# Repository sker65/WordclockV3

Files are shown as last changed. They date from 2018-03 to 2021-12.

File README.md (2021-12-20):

# Links
http://www.leuchtbildshop.net/                                              - Material (Diffusionsfolie)

http://diskussion.christians-bastel-laden.de/index.php                      - Forum (Anleitungen, Folienlieferanten etc)

https://www.mikrocontroller.net/articles/WordClock_mit_WS2812#Frontplatten  - alternative Version (mehr Funktionen)

# changes / extensions by sker65

- added some alternative mapping tables for other word positions (for now only compile time switches)
- added random mode for transitions
- added rainbow color mode.
- added alternative way of spelling minutes (dreiviertel vs. viertel vor)
- make constant "Es ist" display switchable
- code refactored to run with neopixel bus (https://github.com/Makuna/NeoPixelBus) to avoid flickering
- "PROGMEM" aligned to 4 to avoid unaligned access exception
- added new snake transition
- added switch off at night time feature
- cleanup weg ui / JS
- added fill modes for background filling to not just reset the background (big brightness change)
- added moon phase rendering

## compile with arduino ide
to compile with arduino ide install board type "wemos d1 mini" or compatible and install some libraries:
- ArduinoOTA
- ESP8266WiFi
- DNSServer
- ESP8266WebServer
- ESP8266mDNS
- Ticker
- WiFiManager
- NeoPixelBus_by_Makuna
- SPI (maybe alredy core)
- EEPROM (maybe already core)
- ArduinoJson (to be removed, only needed for output redering)
# esp8266wordclock
Wordclock with WS2812B RGB LED modules driven by an ESP8266 module

This is my interpretation of the popular wordclock project. Key features:

- runs on ESP8266 (ESP-07)
- using Arduino framework
- 114 WS2812B LEDs (driven by neopixel bus (formerly AdaFruit_NeoPixel) library)
- WiFi connected
- WiFiManager allows for easy configuration when WiFi network is not yet configured
- NTP client regularly fetches time
- integrated web server handles configuration interface for colors, time server etc.
- automatic brightness using LDR 

front
front

The clock is built into an [IKEA Ribba picture frame](http://www.ikea.com/de/de/catalog/products/00078051/) (€5), the front plate is screen printed to get fully opaque and sharp mask. The time is displayed using words with five minute resolution and the LEDs in the four corners display the minutes between the word changes. Seconds are visualized using the background slowly filling with an alternative color (configurable using the Web interface).



The configuration interface is accessible using any browser at the URL http://wordclock.local and allows to change foreground color, background color, the seconds progress color and other options.

back

The ESP8266 has been wired in dead bug style, I didn't bother to create a PCB for that. [Modules with integrated voltage regulator, buttons, USB and LDR](http://www.cnx-software.com/2015/12/14/3-compact-esp8266-board-includes-rgd-led-photo-resistor-buttons-and-a-usb-to-ttl-interface/) would have been a better option, but delivery from China is so slow and I didn't want to wait that long. The WS2812B LEDs are wired using thin copper wire. When fully powered, the voltage drop on the power wires is quite high and the last LEDs in the chain don't get enough voltage and stop responding. In the next version, I will use thicker wire for the power lines.

The base for the LEDs is made of MDF milled on my CNC mill. It consists of a 12 mm back plate with holes and small rims for the LEDs to rest on and a 12 mm front plate having holes with equal diameter. I added a first diffusor of thin paper between the two plates (to make the LED less visible) and painted the inside of the holes white. On top I added a second diffusor (plastic foil) so the light tunnel gets invisible.

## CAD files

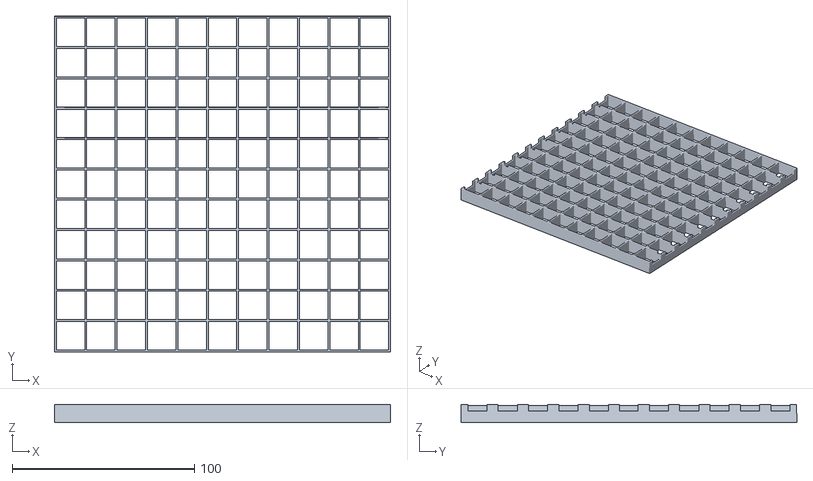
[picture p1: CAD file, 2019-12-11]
_Worldclock 3d Print/Komplett druckbar/3d files/wordclock-grid-complete.stl
184.4 x 184.3 x 10.0

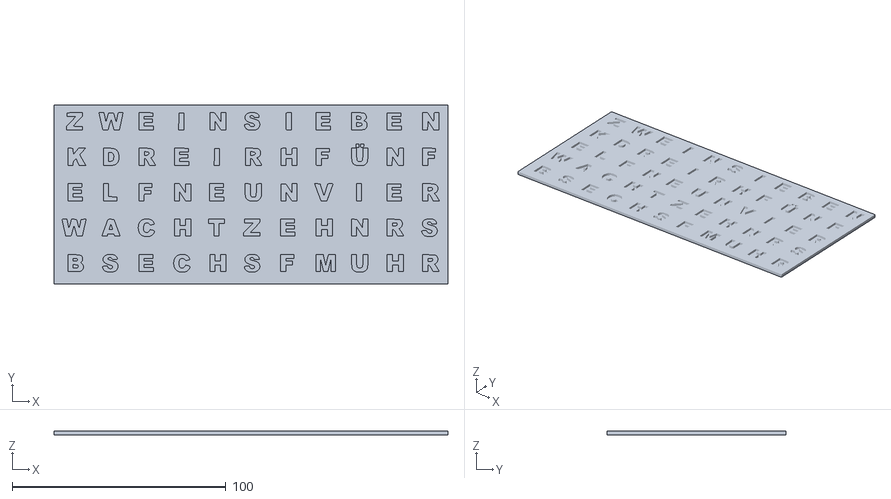
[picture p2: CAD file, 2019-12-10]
_Worldclock 3d Print/Komplett druckbar/3d files/wordclock_shade_full_normal_lower_half.stl
184.4 x 83.8 x 1.80

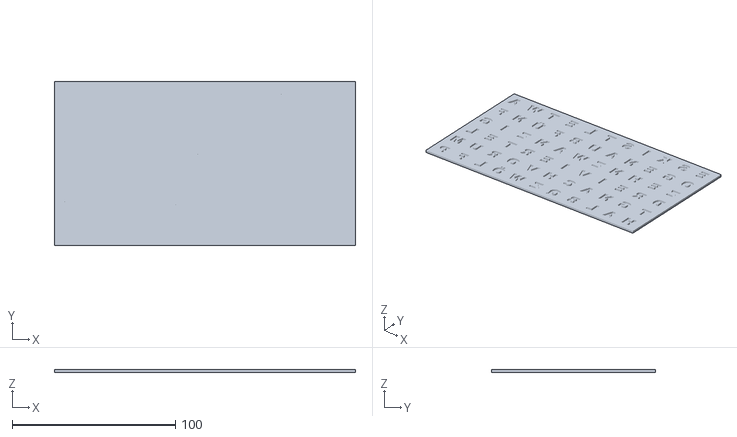
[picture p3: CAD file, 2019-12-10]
_Worldclock 3d Print/Komplett druckbar/3d files/wordclock_shade_full_mirror_upper_half.stl
184.4 x 100.6 x 1.80

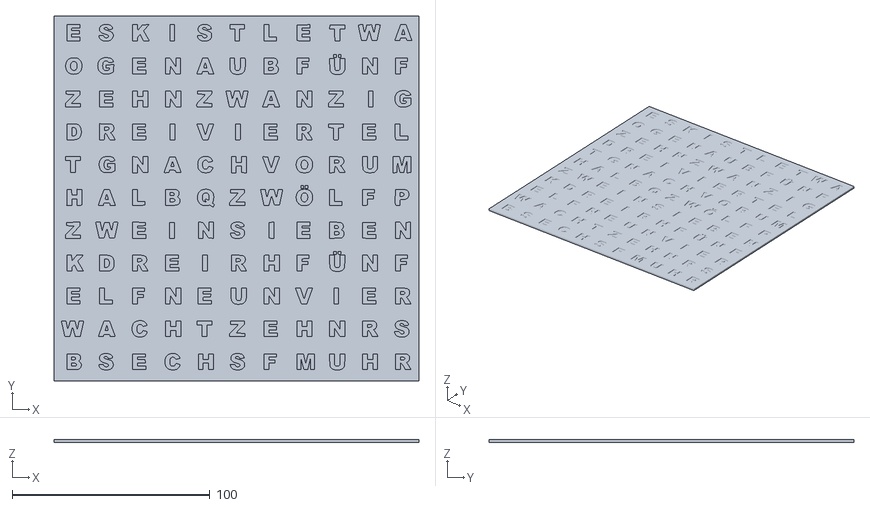
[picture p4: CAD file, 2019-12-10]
_Worldclock 3d Print/Komplett druckbar/3d files/wordclock_shade_full_normal.stl
184.4 x 184.4 x 1.40

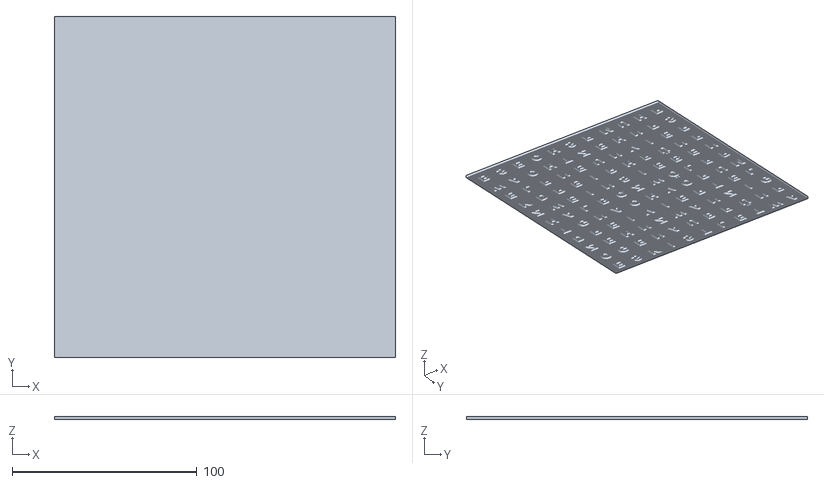
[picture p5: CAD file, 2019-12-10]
_Worldclock 3d Print/Komplett druckbar/3d files/wordclock_shade_full_mirror.stl
184.4 x 184.4 x 1.80

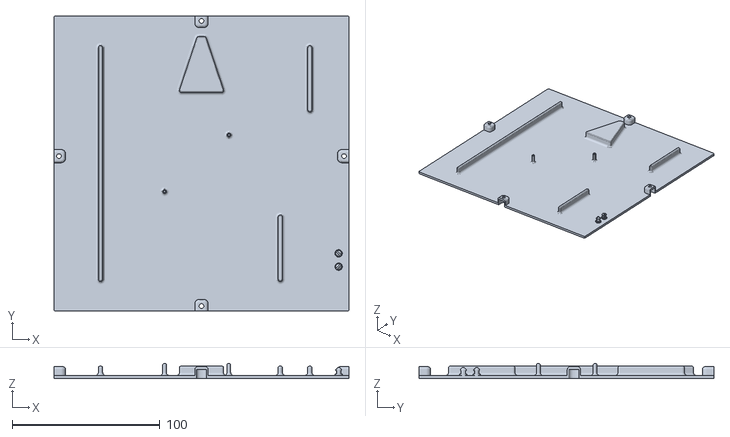
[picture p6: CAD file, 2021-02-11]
_Worldclock 3d Print/druckbar 2/files/Wordclock_Backplate.stl
199.7 x 199.7 x 10.0

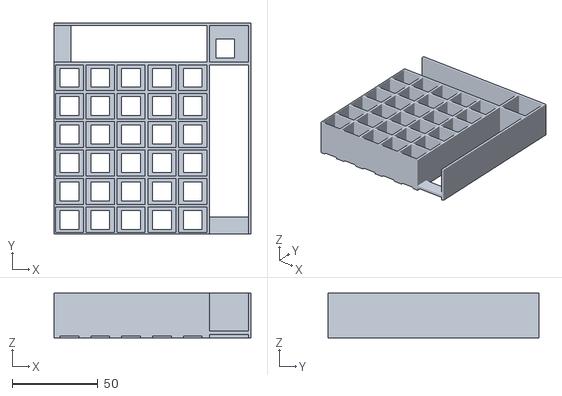
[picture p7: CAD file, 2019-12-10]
_Worldclock 3d Print/für Ikea Rahmen/Lichtgitter1_2x.stl
115.0 x 123.3 x 26.0

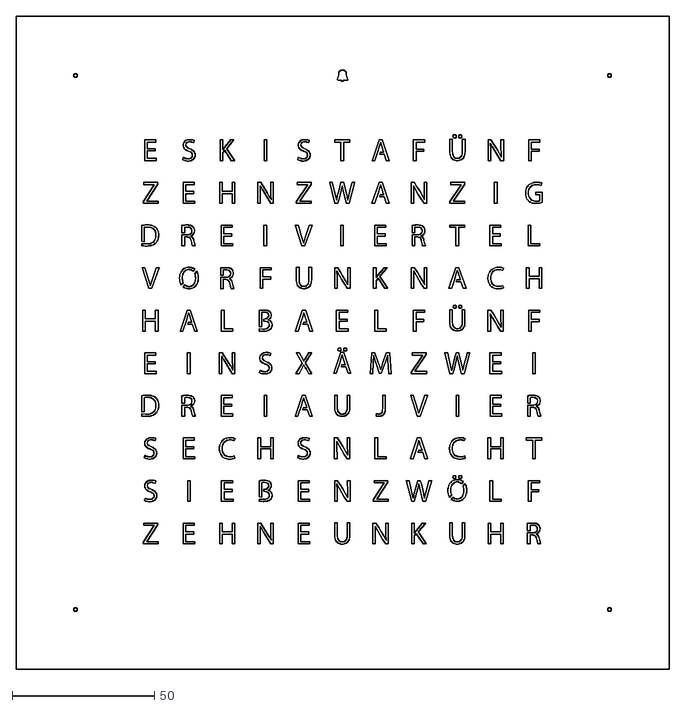
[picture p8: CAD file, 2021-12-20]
Graphics/wortuhr_klein_wecker_frontplatte.dxf
229.9 x 229.9

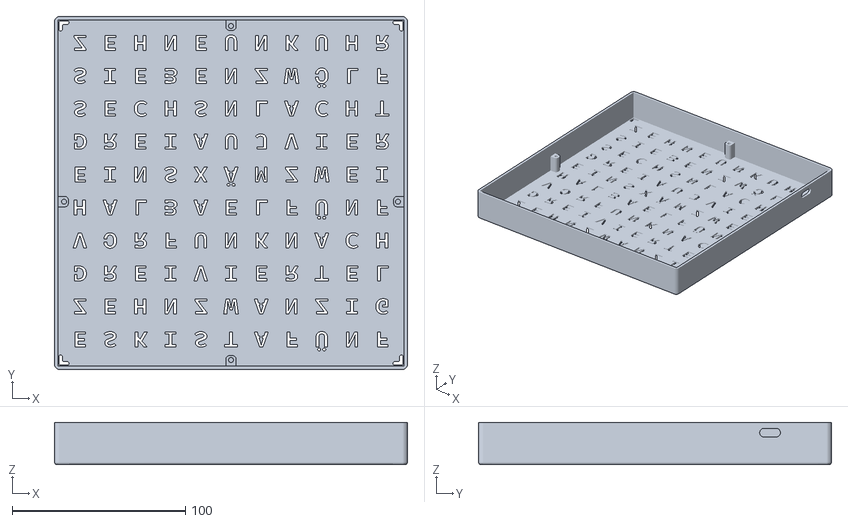
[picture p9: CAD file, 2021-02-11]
_Worldclock 3d Print/druckbar 2/files/Wordclock_Frontcover.stl
204.0 x 204.0 x 24.5

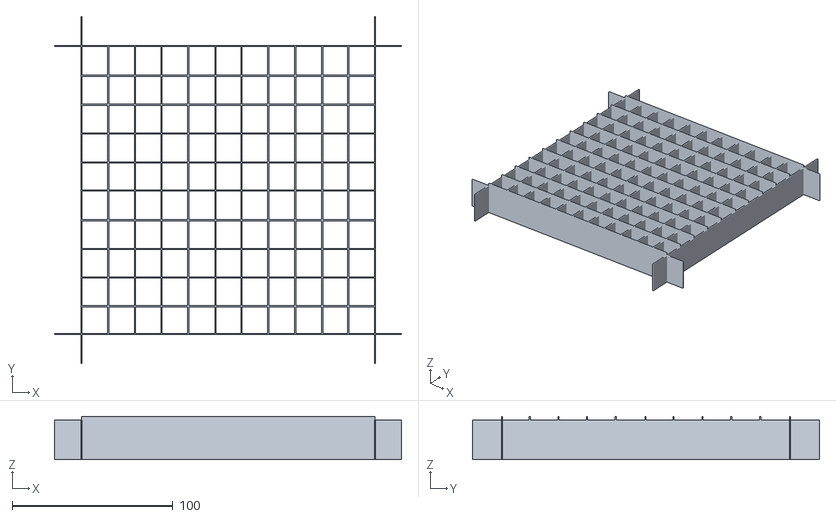
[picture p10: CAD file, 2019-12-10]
_Worldclock 3d Print/für Ikea Rahmen/Wortuhr_Ikea_Lichtgitter.stl
216.0 x 216.0 x 27.0

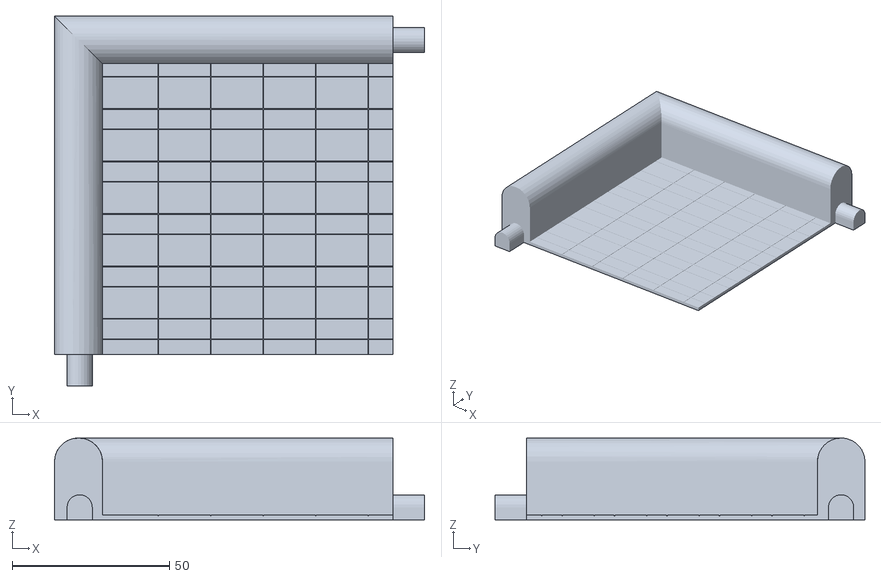
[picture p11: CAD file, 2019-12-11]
_Worldclock 3d Print/Komplett druckbar/3d files/wordclock-case_quater2.stl
117.5 x 117.5 x 26.0

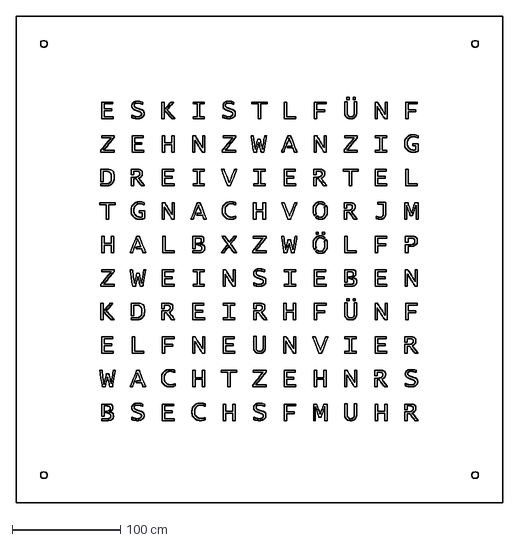
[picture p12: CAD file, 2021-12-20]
Graphics/EdelstahlFrontV2_Faktor10_vergroessert.dxf
450.0 x 450.0 cm

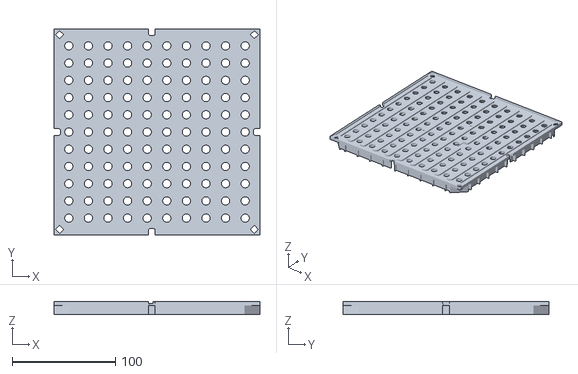
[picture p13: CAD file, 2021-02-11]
_Worldclock 3d Print/druckbar 2/files/wordclock_interior.stl
199.7 x 199.7 x 13.0

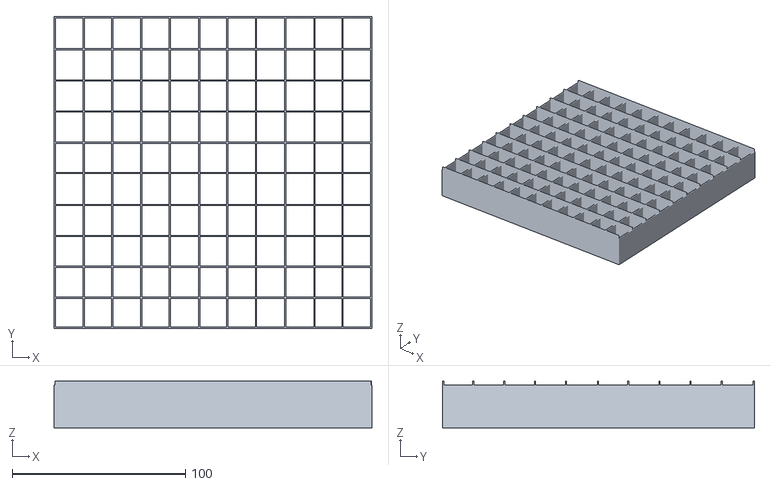
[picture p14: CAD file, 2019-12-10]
_Worldclock 3d Print/für Ikea Rahmen/Wortuhr_Ikea_Lichtgitter passend für drucker.stl
183.5 x 180.2 x 27.0

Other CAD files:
_Worldclock 3d Print/Komplett druckbar/3d files/wordclock_shade_full_mirror_lower_half.stl
_Worldclock 3d Print/Komplett druckbar/3d files/wordclock_shade_full_normal_upper_half.stl
_Worldclock 3d Print/Komplett druckbar/3d files/wordclock-case_quater1.stl
Graphics/Clock_45x45.dxf
.Material/dxfs/180222 T HC Frontplatte groß.dwg
.Material/dxfs/180222 T HC Frontplatte groß.dxf
.Material/dxfs/180222 T HC WordClock Rasterbleche.dwg
.Material/dxfs/180222 T HC WordClock Rasterbleche.dxf
Graphics/EdelstahlFrontV2.dxf
_Worldclock 3d Print/Komplett druckbar/3d files/wordclock-bottom-grid_half.stl
_Worldclock 3d Print/Komplett druckbar/3d files/wordclock-case.stl
_Worldclock 3d Print/Komplett druckbar/3d files/wordclock-case_half.stl
_Worldclock 3d Print/Komplett druckbar/3d files/wordclock-upper-grid_half.stl
_Worldclock 3d Print/Komplett druckbar/3d files/wordclock_shade.stl
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

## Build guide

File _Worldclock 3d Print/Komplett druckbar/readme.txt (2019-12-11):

This is a fully printable case for a word-clock. It is designed for use of LED stripes WS281x with 60 LED/m.
Additional there are needed only a RaspberryPi, a 5V power-supply, some wires and the software from here: https://github.com/xSnowHeadx/word-clock
If using an additional USB-soundcard the device can be used as spectrum-analyzer too (see third picture).

Edit 2017/02/28: wordclock_case_half.stl updated

Edit 2018/08/15: now the cheaper ESP8266 can be used instead the expensive RaspberryPi. A first try of the software is available here: https://github.com/xSnowHeadx/WordClock_ESP8266. There are no audio-functions and (at the moment) no moodlight modus supportet. I also designed a fitting case for the ESP8266: https://www.thingiverse.com/thing:2842012

Print Settings
Printer:

FlashForge Dreamer

Rafts:

No

Supports:

No

Notes:
Print two pieces of the half outer case. On the bottom of the case there are marks for the placement of the LED stripes.
For the grid laying direct on the LED stripes use the parts "bottom_grid". They have slots for the stripes and wires. You need two of them. The upper grids are without slots for better shadowing. Here are 4 pieces necessary. These parts are not at double height to give the possibility for placing additional diffusor foils between them when using a clear shade. Print the grids with black material.
The size of the shades is 184x184mm. If your printer has a sufficient build volume you can use the single parts. If not, use the halved parts. The grids are generally halved for better insertion in the case.

I uploaded all thinkable variants of the shades for your convenience. They must be printed with a resolution of 0.2mm and usually with the plate downwards. The first two layers (the plate) must be printed with a transparent or translucent material. After the second layer the filament has to be changed to black.
The types "normal" can be used, when the letters should be visible even if they are not lighted to show the functionality.
The "mirror" types can be used to hide the letters and show only the lighted. With a translucent white plate and a turquois light setting (RGB 0%,78%,100%) there is an "Apple-effect" possible as to see in the photos.
If you want to use your own print strategy I uploaded the shade for the letters and the plate for the shade separate.
If you don't want to print the shade with the 3D-printer you can print the attached wordclock_shade_laserprinter.bmp with a laserprinter on an overhead-foil and use this as shade. Then you should use additional diffusor foils between the grid layers. This looks like the last photo above. It is recommended to stack two or three of the laserprinted foils for better shadowing.
The wiring of the LED starts at the lower left corner and continues as meander from the lower to the upper stripe (see "word-processor.c" in the source files). It is recommended to draw an additional power connection directly from the lower to the uppermost stripe for evenly brightness of the LED all over the area.

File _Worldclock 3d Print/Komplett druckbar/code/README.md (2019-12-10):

# WordClock ESP8266

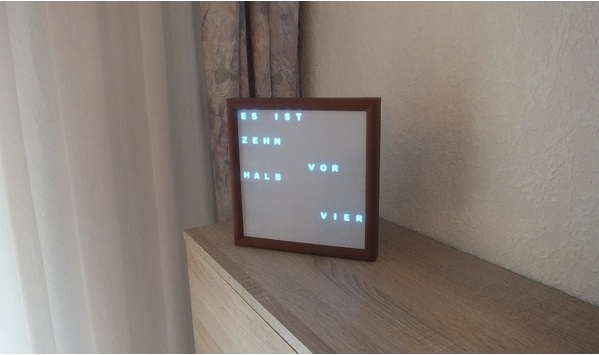
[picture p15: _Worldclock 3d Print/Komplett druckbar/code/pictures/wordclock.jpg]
WordClock


Eine Uhr mit Textanzeige der Uhrzeit basierend auf einem [ESP8266 NodeMCU](https://www.aliexpress.com/item/1PCS-ESP8266-NodeMCU-V3-Lua-WIFI-module-memory-32M-Flash-USB-serial-CH340G/32820380705.html) mit adressierbaren RGB-LED-Stripes und 3D-druckbaren Gehäuseteilen
Die 3D-Modelle für das Gehäuse sind auf thingiverse.com [Uhren-Gehäuse](http://www.thingiverse.com/thing:2137765) und [ESP8266-Gehäuse](https://www.thingiverse.com/thing:2842012) verfügbar.

Die Software ist eine Quick'n Dirty-Adaption meiner für den [RaspberryPi](https://github.com/xSnowHeadx/word-clock) geschriebenen Software natürlich ohne Audio-Funktionen. Sie wird (wenn mal Zeit ist) besser strukturiert und der Web-Server überarbeitet.

## Hardware Setup

Für den Aufbau der Word-Clock werden folgende Komponenten benötigt:

- [ESP8266 NodeMCU](https://www.aliexpress.com/item/1PCS-ESP8266-NodeMCU-V3-Lua-WIFI-module-memory-32M-Flash-USB-serial-CH340G/32820380705.html)
- [WS2811 RGB LED Strip](http://www.ebay.de/itm/WS2812B-LED-Stripe-4m-RGB-60-LEDs-m-Klebestreifen-WS2811-WS2812-/251901768682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): Die Gehäuseteile sind für die Verwendung dieser LED ausgelegt. Bei bestimmten LED-Typen benötigt man einen Pegelwandler von den 3,3V des ESP8266 auf die 5V der LED. 
- optional [ESP8266-Gehäuse](https://www.thingiverse.com/thing:2842012)
- 1 [5V-Netzteil](http://www.amazon.de/gp/product/B004S7U4IO)
- diverse Kabel, Lötwerkzeug
- die 3D-gedruckten Gehäuseteile

# Hardwareaufbau:

Die Verbindung vom ESP8266 zum LED-Stripe kann wie [hier](https://github.com/lvidarte/esp8266/wiki/MicroPython:-NeoPixels) beschrieben erfolgen. Wie abgebildet, kann auch "D5" (Pin 14) als Datenpin verwendet werden. Über die Änderung der Definition für "DATA_PIN" in Zeile 42 der "ino"-Datei kann dieser Pin auf Wunsch auch geändert werden.

Die Spannungsversorgung sollte allerdings nicht vom USB-Port aus, sondern durch ein zusätzliches 5V-Netzteil erfolgen.  

# Software

Das Projekt besteht nur aus einer einzigen "ino"-Datei, welche nach Einbindung der erforderlichen Bibliotheken mit jeder Arduino-tauglichen Entwicklungsumgebung gebaut und geflasht werden kann.

##### Standard libraries
* DNSServer
* Wire
* SPI
* EEPROM
##### Special libraries
* from [ESP8266-core](https://github.com/esp8266/Arduino)
	* ESP8266
	* ESP8266WebServer
	* ESP8266WiFi
* [NTPClient](https://github.com/arduino-libraries/NTPClient)
* [WiFiManager](https://github.com/tzapu/WiFiManager)
* [Time](https://github.com/PaulStoffregen/Time)
* [Timezone](https://github.com/JChristensen/Timezone)
* [FastLED](https://github.com/FastLED/FastLED)

## Web-Interface

Damit auf den ESP8266 zugegriffen werden kann, muß sich dieser im WLAN anmelden können. Das erledigt der WiFi-Manager, dessen Konfiguration auf [dessen Seite](https://github.com/tzapu/WiFiManager#how-it-works) beschrieben ist.

Die Steuerung von WordClock_ESP8266 über Webinterface funktioniert von jedem beliebigen Gerät mit Web-Client (Browser, wget, curl o.Ä.) aus. Hier eine Beschreibung der Befehle und Parameter für das Webinterface (statt "clockip" die IP des des ESP8266 (auslesbar am Router oder über die serielle Konsole) und statt "color" die gewünschten Farben "RED", "GREEN" oder "BLUE" verwenden. "n" wird durch die gewünschten Ziffern ersetzt. "on" schaltet eine Option ein, "off" schaltet sie aus.
Wird hinter dem "=" kein Parameter angegeben, wird statt der aktualisierten Website der Wert des entsprechenden Parameters als Plaintext mit Zeilenumbruch am Ende zurückgegeben. Also "http://clockip/?BRIGHT=" liefert z.B. "BRIGHT=100". Diese Antwort kann dann mit Scripten ausgwertet werden, über welche auch eine Steuerung der Uhr erfolgen kann.

*Modus setzen:*  
`http://clockip?MODE=n`

"n" = 0 bedeutet ostdeutsches Anzeigeformat (zehn vor halb Vier), "n" = 1 westdeutsches Anzeigeformat (zwanzig nach Drei), "n" = 2 startet das diagonale Moodlight, "n" = 3 das flächige Moodlight

*Anzeige von "etwa" steuern:*  
`http://clockip?PREC_ETWA=on`

Bei "on" wird bei größeren 5-Minuten-Rundungsabweichungen "etwa" mit angezeigt, bei "off" nicht
 
*Anzeige von "genau" steuern:*  
`http://clockip?PREC_GENAU=on`

Bei "on" wird bei exakter Minutenübereinstimmung "genau" mit angezeigt, bei "off" nicht
 
*Anzeige von "Uhr" am Ende steuern:*  
`http://clockip?TRAILER=on`

Bei "on" wird am Ende der Textanzeige "Uhr" mit angezeigt, bei "off" nicht
 
*Gesamthelligkeit setzen (0...100%):*  
`http://clockip?BRIGHT=nnn`

*Intensität einer Farbe setzen (0...100%):*  
`http://clockip?color=nnn`

Nicht vergessen: statt "color" die Farben "RED", "GREEN" oder "BLUE" einsetzen.

*Einstellungen speichern*  
`http://clockip?SAVE=`

Die vorher getätigten Einstellungen werden im EEPROM abgespeichert und beim nächsten Einschalten wieder verwendet.

Da ein Web-Server ingtegriert ist, kann die Einstellung der Parameter auch einfach über einen Browser erfolgen. Die Einstellungsseite sieht dann so aus:

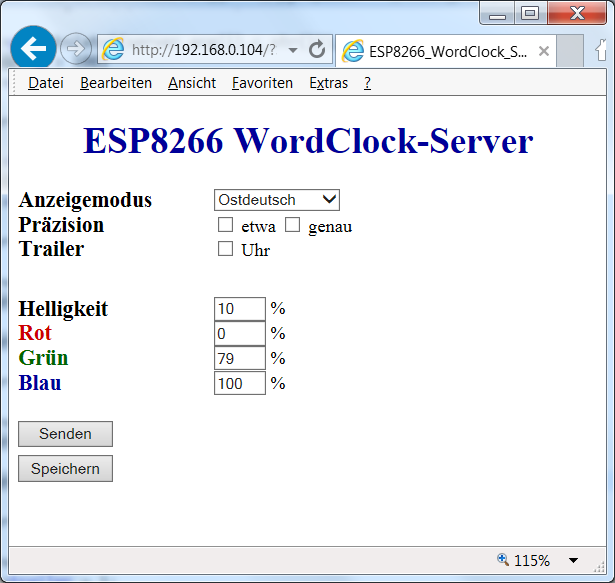
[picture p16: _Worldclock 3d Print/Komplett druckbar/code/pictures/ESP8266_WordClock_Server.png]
WordClock


Die zu sehenden Parameter entsprechen den weiter oben erläuterten. Die getätigten Einstellungen werden erst mit dem Button "Senden" gesammelt an die Uhr übertragen, und mit "Speichern" dort auch für den nächsten Start gespeichert.

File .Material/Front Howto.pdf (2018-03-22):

Dieses HowTo wurde auf Basis von Inkscape 0.91 erstellt. Für Vollständigkeit und Richtigkeit kann keinerlei Haftung oder Garantie übernommen werden. Es soll lediglich eine Anregung sein, sich selbst mit Inkscape zu beschäftigen. Los geht’s.

Nach Öffnen von Inkscape als Erstes im Menu „Datei“ → “Dokumenteneinstellungen…“ Im Karteireiter „Seite“ die Seitengröße auf das gewünschte Maß der Folie einstellen. Darauf achten, dass als Einheit „mm“ gewählt ist und nicht etwa „px“ oder anderes exotisches Zeugs.

Im gleichen Fenster unter dem Reiter „Gitter“ ein neues Raster definieren.

Dies sollte die Abmessungen des gewünschten Rapports haben. Auch hier darauf achten, dass als Einheit „mm“ gewählt ist.

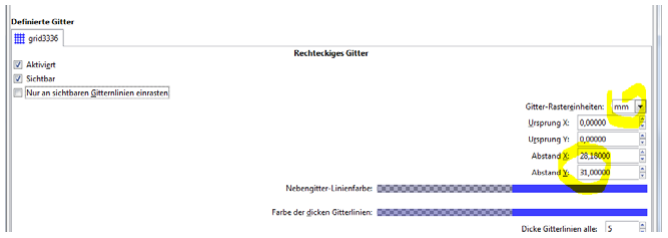
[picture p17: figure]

Kurzer Exkurs zur Berechnung des Rapports (exemplarisch):

Gegeben: LED Streifen mit 64 LED pro Meter. D.h. alle 15,63 mm eine LED. Somit wäre der horizontale Rapport 15,63mm. Wenn nun beispielsweise 11 Buchstaben in eine Reihe sollen so ergibt sich: 15,63mm x 11 = 171,88 mm.

Wenn man weiterhin davon ausgeht, dass 10 Buchstaben in der Vertikalen anordnet sein sollen und die resultierende Anordnung ein Quadrat ergeben soll so ergibt sich: 171,88mm/10=17,19mm. Somit wäre der Rapport und damit das, was als Gittermaß einzutragen wäre: x= 15,63mm, y= 17,19mm.

Jetzt geht’s schon los damit, die gewünschten Buchstaben einzufügen. Damit die Buchstaben an dem soeben erzeugten Gitter einrasten, müssen in dieser Symbolleiste mindestens folgende Buttons

gedrückt sein:

Ist das der Fall sollte das nach Auswählen des Schrifttools beim Überfahren des Rasters mit der Maus

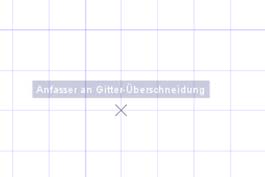
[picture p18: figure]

so aussehen und das Kreuzchen immer schön einschnappen:

Auswählen des Schrifttools (Achtung, es gibt mehrere ähnlich aussehende Icons, nicht verwechseln):

Sollte am rechten Rand eures Bildschirms keine Auswahlmenus dargestellt sein, so kann man das mit

dem | Button nachholen. Sollte dann ungefähr so aussehen:

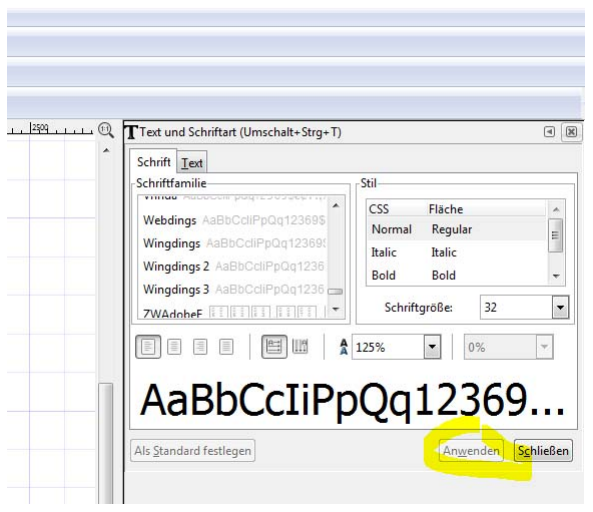
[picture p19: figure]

Ich glaube das Menu ist selbsterklärend.. . Man sollte nur drauf achten, dass man auf den Button „Anwenden“ klicken muss, damit Änderungen an Schriftart, Größe, etc übernommen werden.

Jetzt kann man sich seine gewünschte Buchstabenmatrix zusammenbasteln. Immer schön auf den Rasterpunkt klicken und den gewünschten Buchstaben setzen.

Es ist an dieser Stelle erstmal egal wo man die Matrix positioniert, das Ausrichten kommt später.

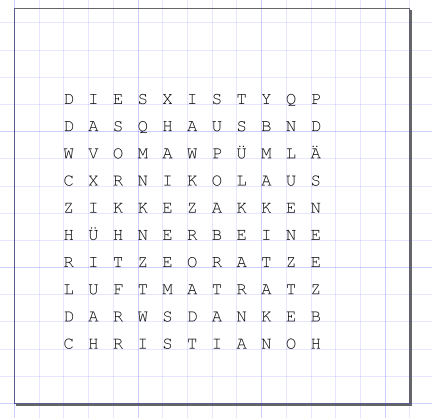
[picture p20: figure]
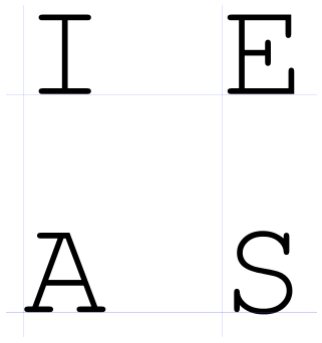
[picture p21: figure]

Bei genauer Betrachtung sieht man, dass die Buchstaben jeweils rechts vom Ankerpunkt ausgerichtet wurden. Dies kann man jetzt ändern auf zentriert.

Dazu zieht man mit dem Objekt‐Auswahl‐tool | einen Rahmen um alle Buchstaben, so dass
sie ausgewählt sind.

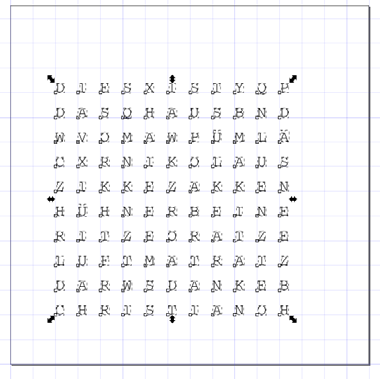
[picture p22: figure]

Nun kann man im Schriftendialog auf der rechten Seite alles wie gewünscht anpassen. Schriftart, Größe, Style… und eben auch die Ausrichtung. Dies geschieht mit diesem Button:

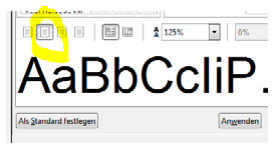
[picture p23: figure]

Wenn alles eingestellt ist, nicht vergessen auf | zu
klicken. Ich hab jetzt beispielhaft mal Arial, Schriftgrad 59, zentriert gewählt und das Ergebnis sieht so aus:

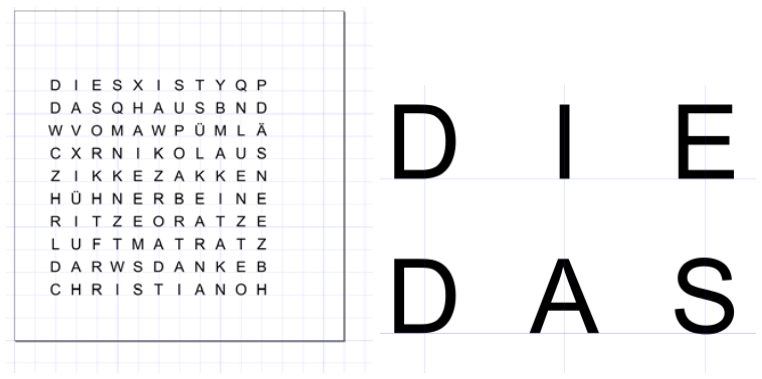
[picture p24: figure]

Man erkennt schön,
dass die Buchstaben jetzt zentriert auf dem Gitter stehen.

Um das ganze jetzt in die Seite einzupassen wird der Buchstabensalat wieder markiert (Rechteck

aufziehen mit ). Jetzt werden die Buchstaben gruppiert um sie in ihrer Gesamtheit in die Seite einzupassen:

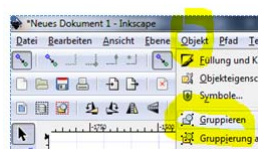
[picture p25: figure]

Zum Ausrichten wählt man aus der Symbolleiste | woraufhin
sich rechts ein Menu einblendet (so es nicht schon da war). In Selbigem wählt man eine sowohl horizontal als auch vertikal zentrierte Ausrichtung. Wichtig hierbei ist, das „relativ zu: Seite“ ausgewählt ist!

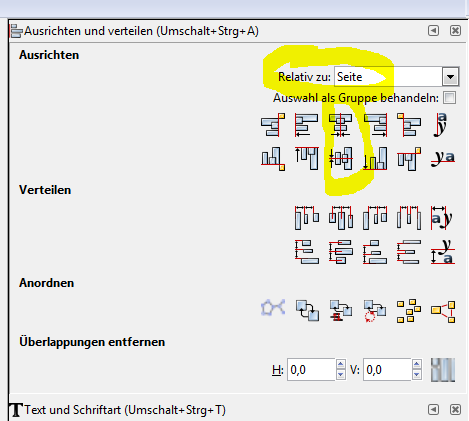
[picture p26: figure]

Jetzt sollte datt janze so aussehen und schön zentriert in der Mitte der Seite platziert sein:

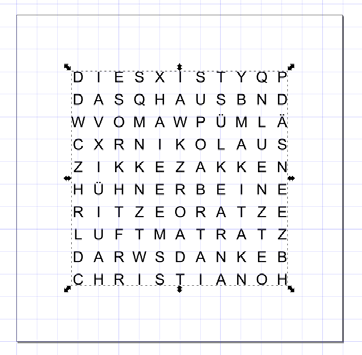
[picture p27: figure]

Nun brauchen wir die Gruppierung der Buchstaben nicht mehr und lösen sie auf:

Buchstabengruppe auswählen Menu „Objekt“ → Gruppierung aufheben.

Jetzt geht es weiter mit den Eckpunkten und dem Hintergrund. Eigentlich könnte man alle Elemente in eine Ebene packen aber es ist übersichtlicher, für den Hintergrund und die Eckpunkte jeweils eine neue Ebene anzulegen. Also los. Zunächst braucht man das Ebenenmenu, dass man sich mit

an den rechten Bildrand zaubert. Sieht dann so aus:

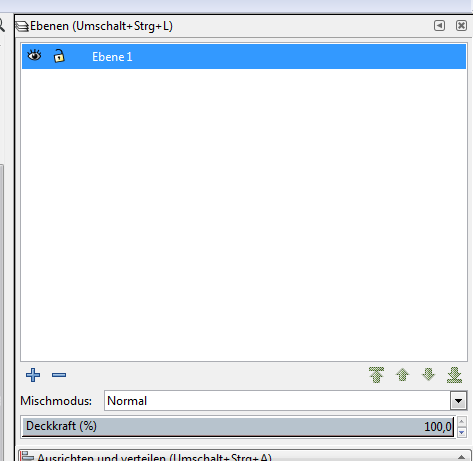
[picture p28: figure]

Hier kann man zunächst einmal die bestehende „Ebene 1“ durch klick miut rechter Maustaste auf den Namen umbenennen in z.B. „Buchstaben“. Eien neue

Ebene erstellt man durch klick auf | .

Diese nennt man „Hintergrund“ und plaziert sie unter der aktuellen Ebene.

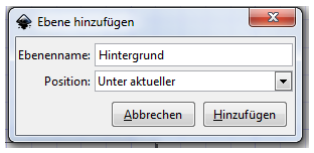
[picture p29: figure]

Wenn man gerade dabei ist kann man auch gleich eine weitere Ebene für die Eckpunkte erstellen.

Gleiches procedere; klick auf | , dann Name und Position festlegen.

Sollte dann ungefähr so aussehen:

Jetzt wählt man die Ebene „Hintergrund“ durch Mausklick aus. Alle Aktionen werden somit nur auf

dieser Ebene ausgeführt.

Durch Auswahl des Rechteck Tools | ziehen wir ein beliebig großes Rechteck auf:

Die Größe des Rechecks lässt sich nun ändern in die gewünschten Maße unserer Frontplatte (darauf achten, das als Einheit Millimeter ausgewählt ist:

Jetzt sieht es so aus und man möchte das Quadrat in die Seite einpassen:

Dazu wählt man wieder die horizontale und vertikale Zentrierung aus dem „Ausrichten“ Menu.

Wichtig auch hier wieder, dass „Relativ zu Seite“ gewählt ist

Jetzt überdeckt das schwarze Ding alles, was nicht nett ist. Um das zu ändern setzt man im Ebenenmenu die Deckkraft dieser Ebene auf irgendwas um 50%.

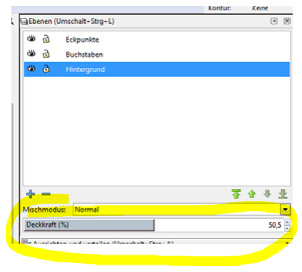
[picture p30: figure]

Im Ergebnis wird das alles ein wenig transparent.

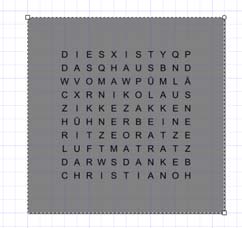
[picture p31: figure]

Anmerkung: Streng genommen ist der Hintergrund überflüssig, da ja nur die Pfade für die Buchstaben und Ecken benötigt werden aber irgendwie hatte ich das Bedürfnis ihn trotzdem anzulegen…

Im nächsten Schritt werden die Eckpunkte gesetzt. Hierzu wechselt man in die entsprechende Ebene

Jetzt wird ein Kringel gezeichnet. . Wenn man beim zeichnen die „STRG“ Taste gedrückt hält, gibt’s schöne Kreise anstelle von Ellipsen… Wo man den Kreis hinmalt ist wieder mal egal, positionieren erfolgt jetzt:

Der Durchmesser für die Kreis soll 2 mm betragen. Abstand von horizontalen und vertikalen Seitenbegrenzungen jeweils z.B. 25 mm.

Zunächst passt man die Größe an (dazu muss der Kreis natürlich ausgewählt sein):

Auch hier wieder drauf achten, dass „mm“ als Einheit gewählt ist.

Jetzt richtet man den Kreis aus. Für oben links ergeben sich folgende Eckwerte:

X: 24 mm, Y: 424 mm. Somit erzeugt man einen Kreis mit zwei Millimetern Durchmesser, dessen Mittelpunkt genau 25mm von der oberen und der linken Kante entfernt ist.

Für die anderen drei Kreise verfährt man analog:

Links oben: x= 24, y=424

Rechts oben: x=424, y=424

Links unten: x=24, y=24

Rechts unten: x=424, y=24

Bevor man jetzt die letzen Schritte macht (vereinigen der Ebenen, umwandeln in Pfade) sollte man die Datei abspeichern, da man hier jetzt (noch) die Möglichkeit hat, relativ schnell Schriftart, Schriftgröße oder andere Parameter zu ändern falls man verschiedene Frontplatten machen möchte.

Jetzt kann man die Objekte einer Ebene jeweils auf die darunterliegende Ebene verschieben. Also

„Eckpunkte“ auswählen, mit STRG‐A alle Objekte auswählen und im Menu „Ebene“ → Auswahl zur darunterliegenden Ebene verschieben wählen.

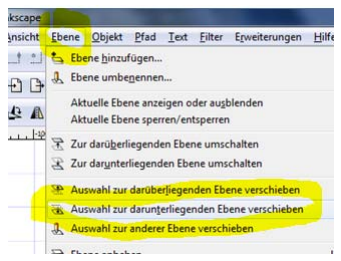
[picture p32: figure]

Die Ebene „Eckpunkte“ ist somit leer und kann gelöscht werden (rechte Maustaste auf Ebenennamen=> aktuelle Ebene löschen).

Bevor man jetzt die Ebene „Buchstaben“ mit der Ebene „Hintergrund verschmilzt empfiehlt es sich, die Farbe von Eckpunkten und Buchstaben in „Weiß“ zu ändern.

Dazu die Ebene „Buchstaben“ auswählen und mit STRG‐A alle Objekte in dieser Ebene markieren

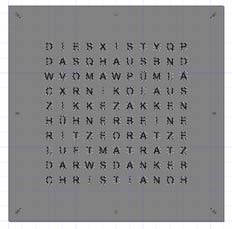
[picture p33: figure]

Nun kann man unten links am Bildschirm die Farbe für die Füllung in „weiß“ ändern:

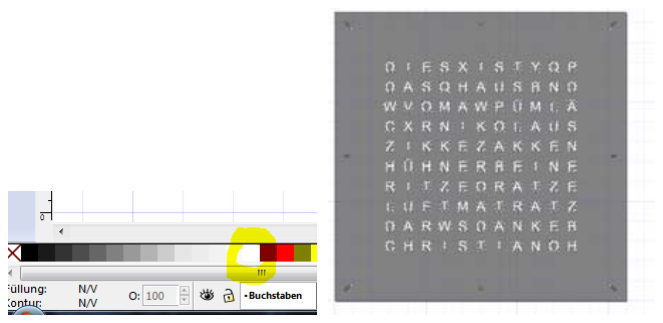
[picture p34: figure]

Wenn alle Objekte noch markiert sind (ansonsten STRG‐A) kann man sie nun, wie oben schon beschrieben, in die darunterliegende Ebene „Hintergrund“ verschieben. Menu „Ebene“ → „Auswahl zu darunterliegender Ebene verschieben“. Da die Ebene „Buchstaben“ jetzt leer ist, kann man auch diese Ebene löschen. Es bleibt also nur die Hintergrund‐Ebene bestehen, die jetzt alle Objekte enthält. Last not least kann man die Deckkraft dieser Ebene wieder auf 100% setzen, so dass das

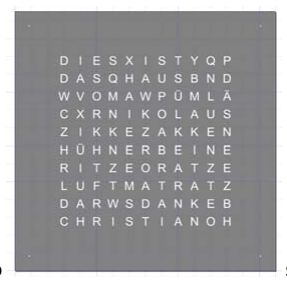
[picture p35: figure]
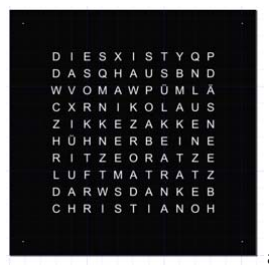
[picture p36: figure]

Ergebnis nicht so | sondern so | aussieht.

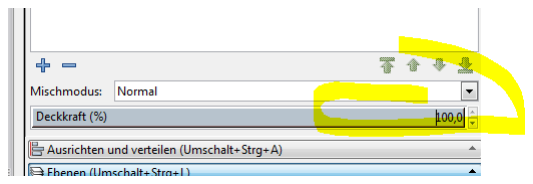
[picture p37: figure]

Sooooo. Fast fertig. Im allerletzen Schritt wandeln wir alle Objekte in Pfade um, die dem Plotte dann als Schnittmarken dienen. Dazu markiert man alle Objekte mit STRG‐A und wählt im Menu „Pfad“ → Objekt in Pfad umwandeln.

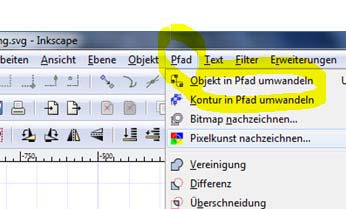
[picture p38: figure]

Fertig.

Beim Abspeichern als *.svg sollte man jetzt einen neuen Namen vergeben, damit man die Datei‐ Version mit Text statt Pfaden für spätere Zwecke nicht verloren geht. Ist der Text erstmal in Pfade umgewandelt, kann man ihn nicht mehr ändern (Schriftart etc) und man fängt bei null an...

Im allerletzten Schritt erstellen wir die pdf‐Datei. Dazu wählt man einfach „Speichern unter“ und wählt als Dokumentenformat „Portable Document Format (*.pdf)“ aus. So nicht bereits ausgewählt kann man hier im aufpoppenden Menu zur Sicherheit nochmals „Text in Pfade umwandeln“

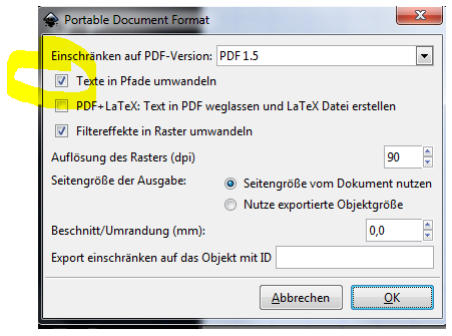
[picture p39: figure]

auswählen.

Viel Spaß beim „Nachbau“ und der Kreation von lustigen, eigenen Leuchtbildern ;‐).

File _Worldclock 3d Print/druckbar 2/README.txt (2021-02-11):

Wordclock Wortuhr  by N1cls on Thingiverse: https://www.thingiverse.com/thing:4693081

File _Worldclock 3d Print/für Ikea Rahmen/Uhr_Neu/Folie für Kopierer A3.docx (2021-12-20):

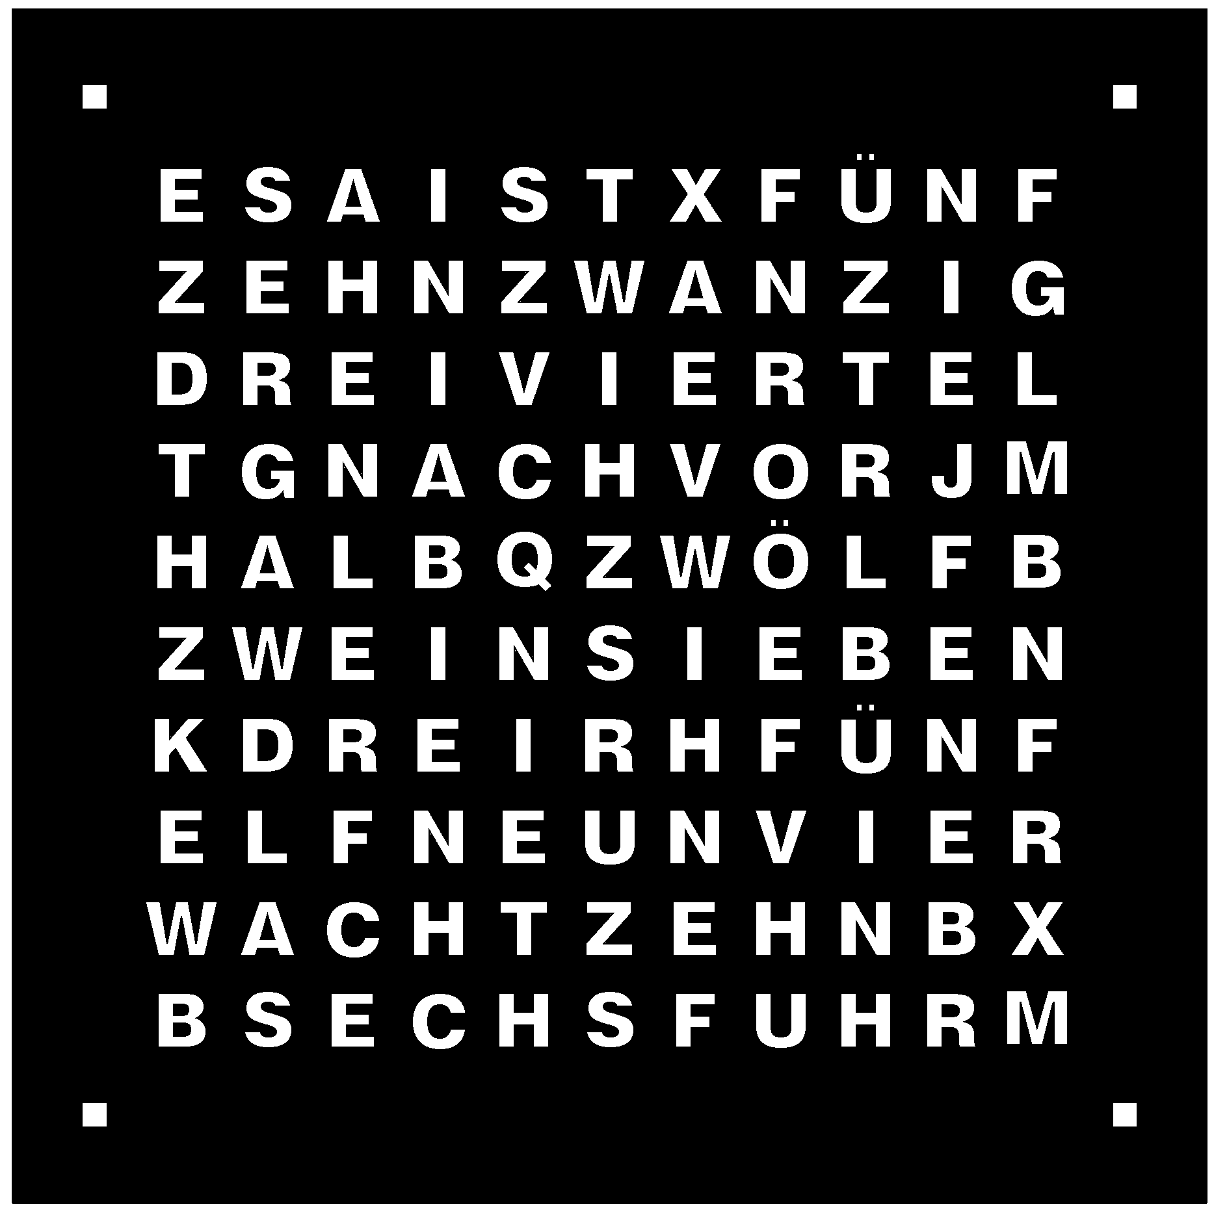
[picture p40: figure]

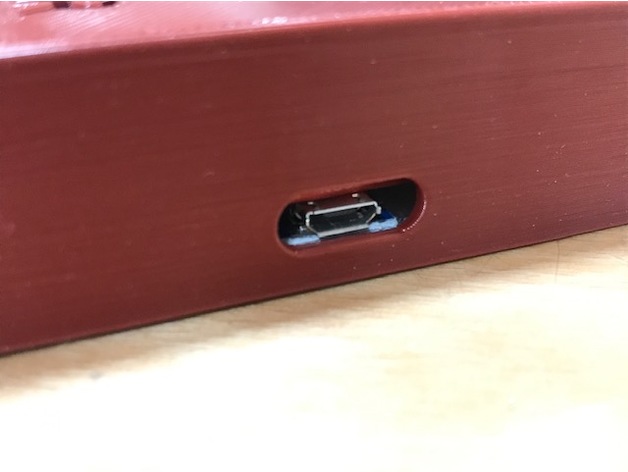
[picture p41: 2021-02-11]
_Worldclock 3d Print/druckbar 2/images/image0.jpeg

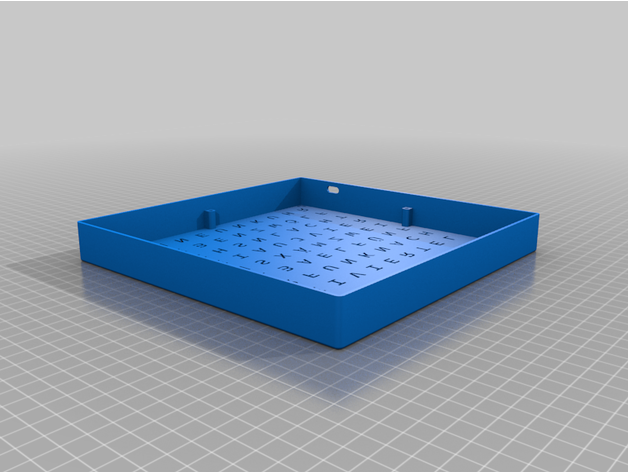
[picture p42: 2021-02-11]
_Worldclock 3d Print/druckbar 2/images/Wordclock_Frontcover.png

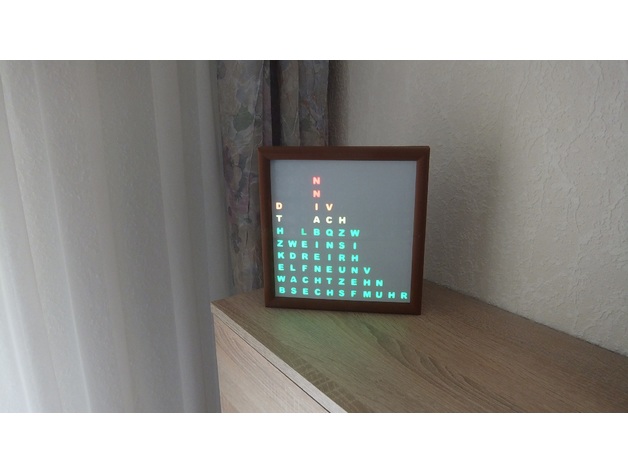
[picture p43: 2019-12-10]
_Worldclock 3d Print/Komplett druckbar/images/0b5793e00879ed53800c6195a527a1c3_preview_featured.JPG

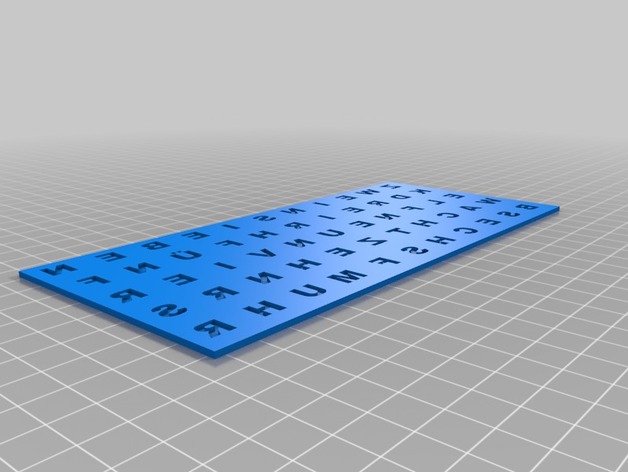
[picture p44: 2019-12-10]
_Worldclock 3d Print/Komplett druckbar/images/ed8f483b9f0b0c1371c34fae073dd86d_preview_featured.jpg

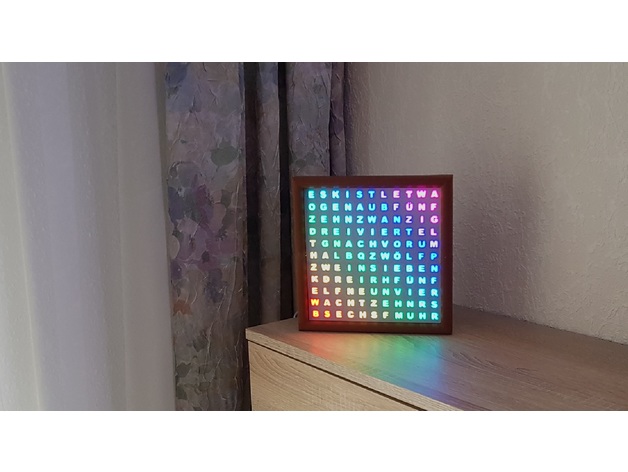
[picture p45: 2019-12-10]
_Worldclock 3d Print/Komplett druckbar/images/0e1fb69278d4a3fa63f1522dfff25e62_preview_featured.jpg

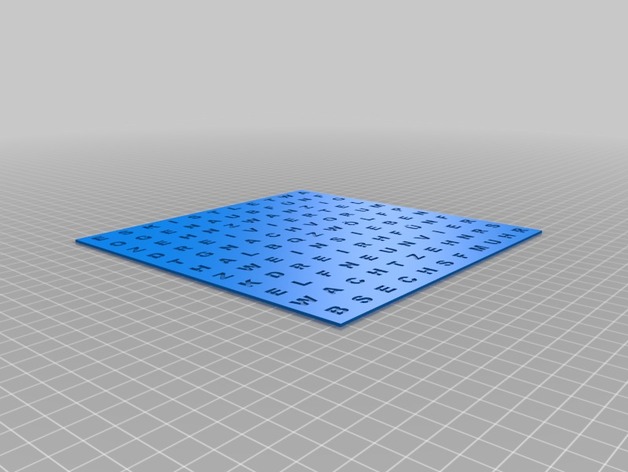
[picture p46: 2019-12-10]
_Worldclock 3d Print/Komplett druckbar/images/4cca726325ded3b8f7c283fea58d291f_preview_featured.jpg

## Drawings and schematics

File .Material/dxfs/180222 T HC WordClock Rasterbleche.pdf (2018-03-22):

## Rasterblech horizontal 11x pro Uhr

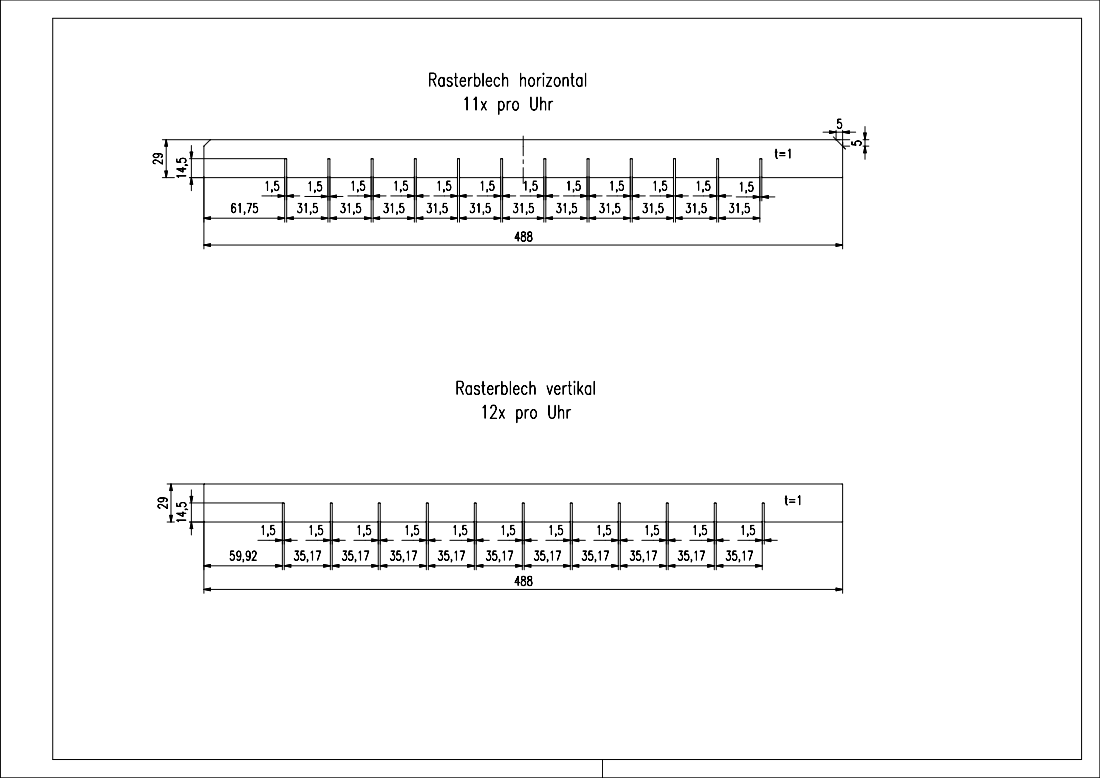
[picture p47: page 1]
Rasterblech vertikal 12x pro Uhr

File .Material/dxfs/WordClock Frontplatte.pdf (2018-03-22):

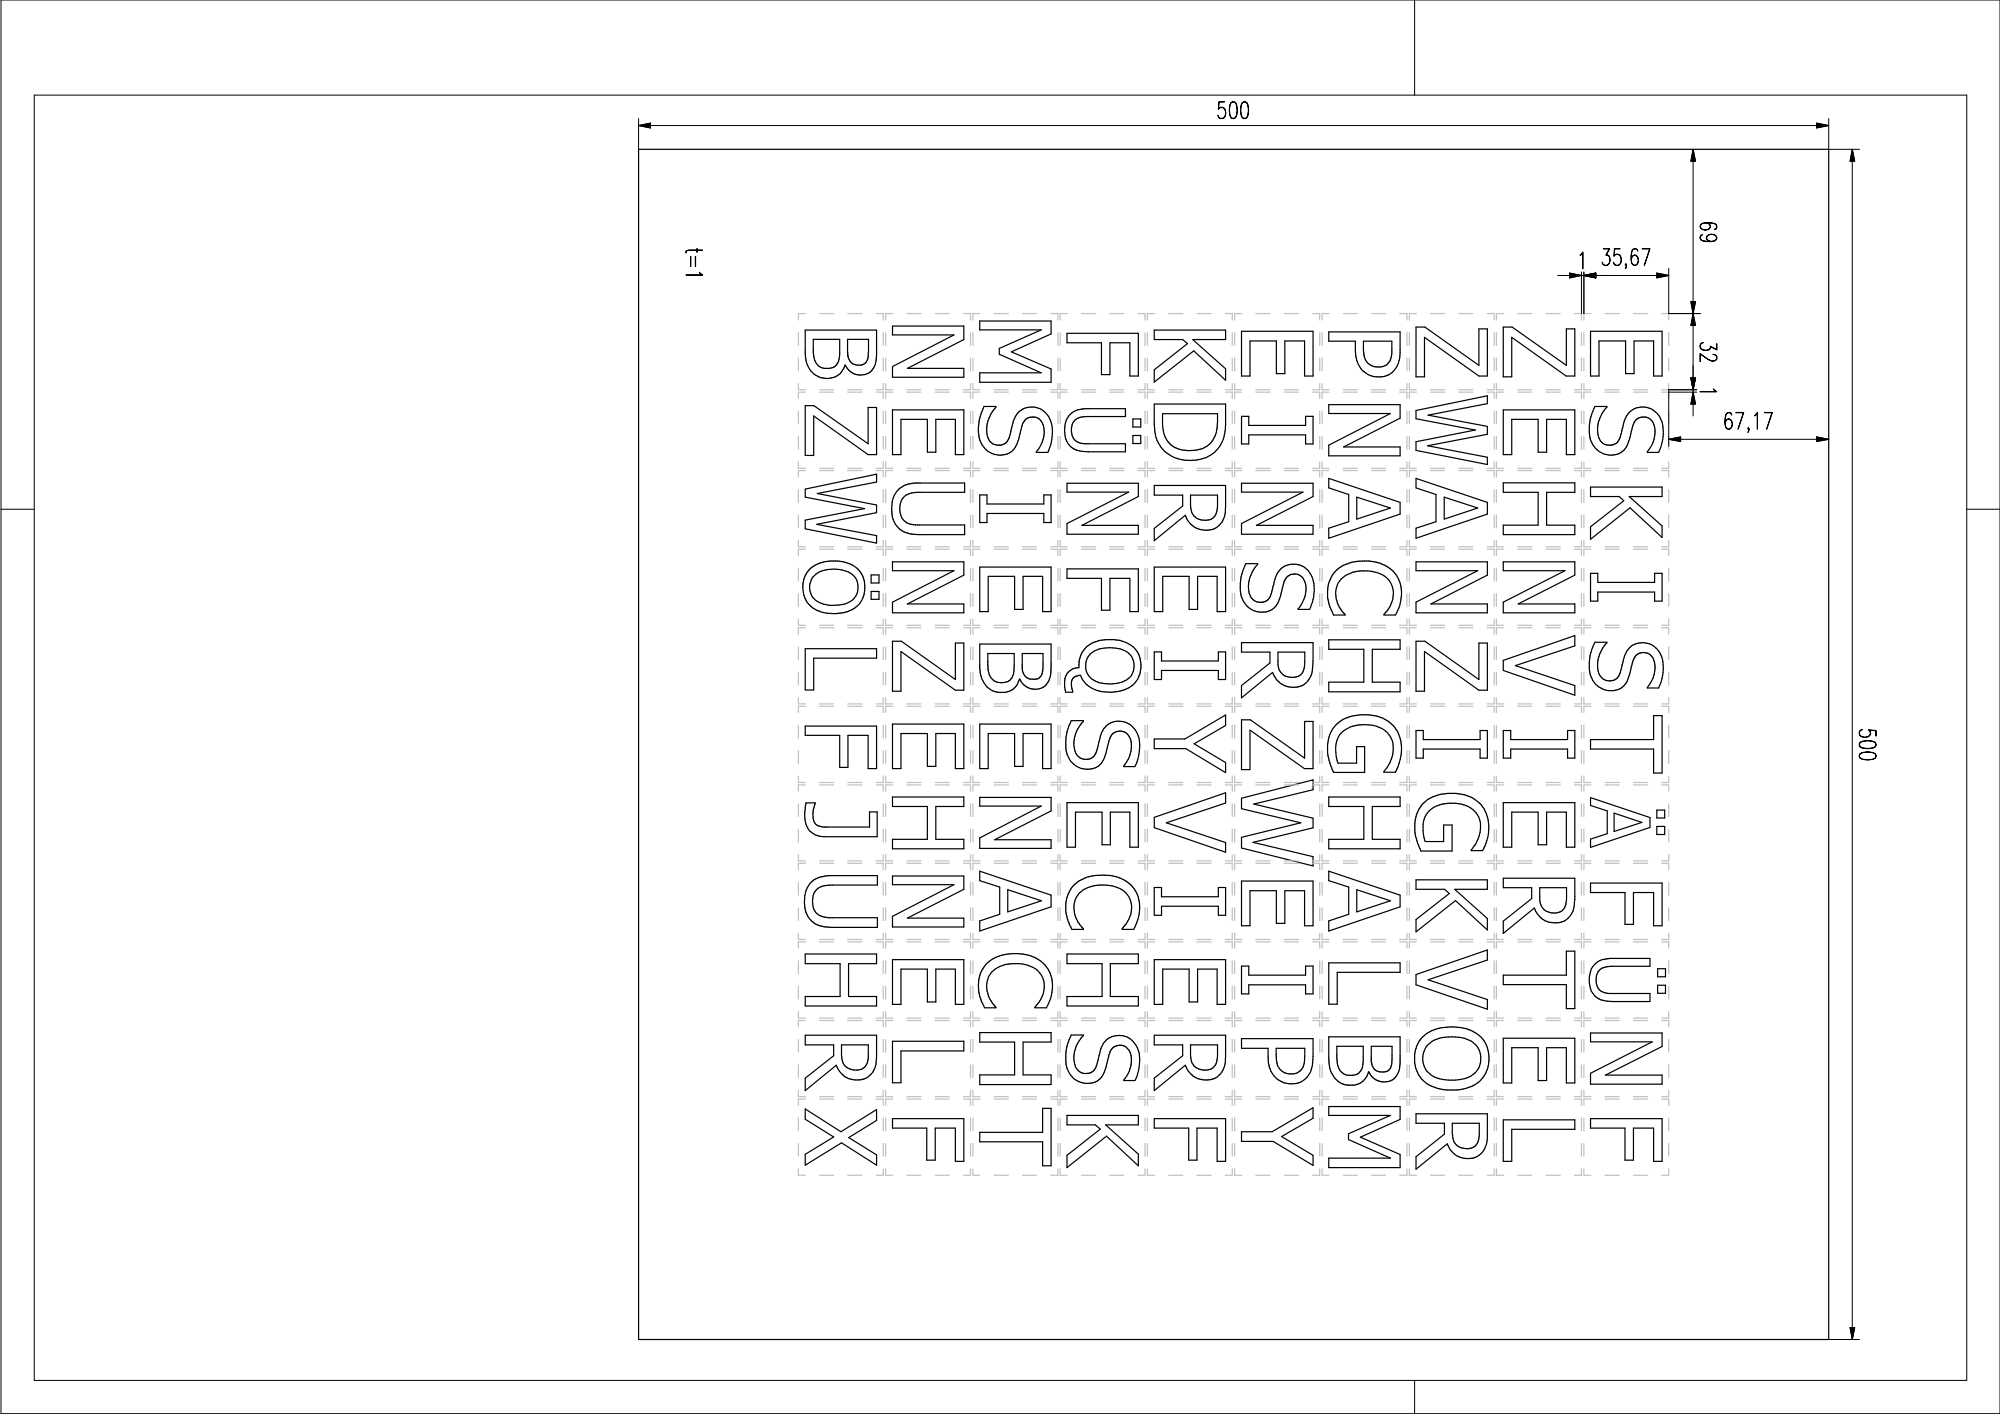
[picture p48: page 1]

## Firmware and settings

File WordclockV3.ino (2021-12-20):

// Copyright (C) 2016 Thoralt Franz, https://github.com/thoralt
// also (C) 2021 by Stefan Rinke, https://github.com/sker65
//
//  This project is the firmware for a Wordclock consisting of 114 WS2812B LEDs.
//  It implements:
//   - NTP client for time synchronization
//   - a web server for configuration access
//   - mDNS client for easy discovery
//   - class for easy LED access with fading
//   - OTA (over the air) updates
//   - WiFi manager for easy configuration in unknown WiFi networks
//
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
// You should have received a copy of the GNU General Public License
// along with this program.  If not, see <http://www.gnu.org/licenses/>.
#include <ArduinoOTA.h>
#include <ESP8266WebServer.h>
#include <ESP8266WiFi.h>
#include <ESP8266mDNS.h>
#include <Ticker.h>
#include <WiFiManager.h>

#include "brightness.h"
#include "config.h"
#include "ledfunctions.h"
#include "ntp.h"
#include "webserver.h"

#define DEBUG( ... )                                                                                                   \
	Serial.printf( __VA_ARGS__ );                                                                                        \
	if( telnetClient.connected() )                                                                                       \
		telnetClient.printf( __VA_ARGS__ );

#define LED_RED 15
#define LED_GREEN 12
#define LED_BLUE 13
#define LED_BUILTIN 2

//---------------------------------------------------------------------------------------
// Network related variables
//---------------------------------------------------------------------------------------
int OTA_in_progress = 0;

WiFiServer telnetServer( 23 );
WiFiClient telnetClient;

//---------------------------------------------------------------------------------------
// Timer related variables
//---------------------------------------------------------------------------------------
#define TIMER_RESOLUTION 10
#define HOURGLASS_ANIMATION_PERIOD 100
Ticker timer;
int h = 0;
int m = 0;
int s = 0;
int ms = 0;
int year = 0;
int month = 0;
int day = 0;
int lastSecond = -1;
bool timeVarLock = false;
bool startup = true;

int hourglassState = 0;
int hourglassPrescaler = 0;

int updateCountdown = 25;

//---------------------------------------------------------------------------------------
// timerCallback
//
// Increments time, decrements timeout and NTP timer
//
// -> --
// <- --
//---------------------------------------------------------------------------------------
void timerCallback() {
	// update time variables
	if( !timeVarLock ) {
		timeVarLock = true;
		ms += TIMER_RESOLUTION;
		if( ms >= 1000 ) {
			ms -= 1000;
			if( ++s > 59 ) {
				s = 0;
				if( ++m > 59 ) {
					m = 0;
					if( ++h > 23 )
						h = 0;
				}
			}
		}
		timeVarLock = false;
	}

	// decrement delayed EEPROM config timer
	if( Config.delayedWriteTimer ) {
		Config.delayedWriteTimer--;
		if( Config.delayedWriteTimer == 0 )
			Config.delayedWriteFlag = true;
	}

	// blink onboard LED if heartbeat is enabled
	if( ms == 0 && Config.heartbeat )
		digitalWrite( LED_BUILTIN, LOW );
	else
		digitalWrite( LED_BUILTIN, HIGH );

	hourglassPrescaler += TIMER_RESOLUTION;
	if( hourglassPrescaler >= HOURGLASS_ANIMATION_PERIOD ) {
		hourglassPrescaler -= HOURGLASS_ANIMATION_PERIOD;
		if( ++Config.hourglassState >= HOURGLASS_ANIMATION_FRAMES )
			Config.hourglassState = 0;

		// trigger LED processing for hourglass during startup
		if( startup )
			LED.process();
	}
}

//---------------------------------------------------------------------------------------
// configModeCallback
//
// ...
//
// ->
// <- --
//---------------------------------------------------------------------------------------
void configModeCallback( WiFiManager* myWiFiManager ) {
	LED.setMode( DisplayMode::wifiManager );
	Serial.println( "Entered config mode" );
	Serial.println( WiFi.softAPIP() );
	Serial.println( myWiFiManager->getConfigPortalSSID() );
}

//---------------------------------------------------------------------------------------
// NtpCallback
//
// Is called by the NTP class upon successful reception of an NTP data packet. Updates
// the global hour, minute, second and millisecond values.
//
// ->
// <- --
//---------------------------------------------------------------------------------------
void NtpCallback( uint8_t _h, uint8_t _m, uint8_t _s, uint8_t _ms, int _year, int _month, int _day ) {
	Serial.println( "NtpCallback()" );

	// wait if timer variable lock is set
	while( timeVarLock )
		delay( 1 );

	// lock timer variables to prevent changes during interrupt
	timeVarLock = true;
	h = _h;
	m = _m;
	s = _s;
	ms = _ms;
	year = _year;
	month = _month;
	day = _day;
	timeVarLock = false;
}

void setLED( unsigned char r, unsigned char g, unsigned char b ) {
#ifdef HAVE_RGB_LEDS
	digitalWrite( LED_RED, r );
	digitalWrite( LED_GREEN, g );
	digitalWrite( LED_BLUE, b );
#endif
}

//---------------------------------------------------------------------------------------
// setup
//
// Initializes everything
//
// -> --
// <- --
//---------------------------------------------------------------------------------------
void setup() { // ESP8266 LED
	pinMode( LED_BUILTIN, OUTPUT );
#ifdef HAVE_RGB_LEDS
	pinMode( LED_RED, OUTPUT );
	pinMode( LED_GREEN, OUTPUT );
	pinMode( LED_BLUE, OUTPUT );
#endif

	setLED( 1, 0, 0 );

	// serial port
	Serial.begin( 115200 );
	Serial.println();
	Serial.println();
	Serial.println( "ESP8266 WordClock setup() begin" );

	// timer
	Serial.println( "Starting timer" );
	timer.attach( TIMER_RESOLUTION / 1000.0, timerCallback );

	// configuration
	Serial.println( "Loading configuration" );
	Config.begin();

	// LEDs
	Serial.println( "Starting LED module" );
	LED.begin( D4 );
	LED.setMode( DisplayMode::yellowHourglass );

	// WiFi
	wifi_station_set_hostname( "WordClock" );
	Serial.println( "Initializing WiFi" );
	WiFiManager wifiManager;
	wifiManager.setAPCallback( configModeCallback );
	if( !wifiManager.autoConnect( "WordClock" ) ) {
		Serial.println( "failed to connect, timeout" );
		delay( 1000 );
		ESP.reset();
	}

	setLED( 0, 0, 1 );

	// OTA update
	Serial.println( "Initializing OTA" );
	ArduinoOTA.setPort( 8266 );
	ArduinoOTA.setHostname( "WordClock" );
	// ArduinoOTA.setPassword((const char *)"123");
	ArduinoOTA.onStart( []() {
		LED.setMode( DisplayMode::update );
		Config.updateProgress = 0;
		OTA_in_progress = 1;
		Serial.println( "OTA Start" );
	} );
	ArduinoOTA.onEnd( []() {
		LED.setMode( DisplayMode::updateComplete );
		Serial.println( "\nOTA End" );
	} );
	ArduinoOTA.onProgress( []( unsigned int progress, unsigned int total ) {
		LED.setMode( DisplayMode::update );
		Config.updateProgress = progress * 110 / total;
		Serial.printf( "OTA Progress: %u%%\r\n", ( progress / ( total / 100 ) ) );
	} );
	ArduinoOTA.onError( []( ota_error_t error ) {
		LED.setMode( DisplayMode::updateError );
		Serial.printf( "OTA Error[%u]: ", error );
		if( error == OTA_AUTH_ERROR )
			Serial.println( "Auth Failed" );
		else if( error == OTA_BEGIN_ERROR )
			Serial.println( "Begin Failed" );
		else if( error == OTA_CONNECT_ERROR )
			Serial.println( "Connect Failed" );
		else if( error == OTA_RECEIVE_ERROR )
			Serial.println( "Receive Failed" );
		else if( error == OTA_END_ERROR )
			Serial.println( "End Failed" );
	} );
	ArduinoOTA.begin();

	// NTP
	Serial.println( "Starting NTP module" );
	NTP.begin( Config.ntpserver, NtpCallback, 1, true );

	// web server
	Serial.println( "Starting HTTP server" );
	HttpServer.begin();

	telnetServer.begin();
	telnetServer.setNoDelay( true );

	startup = false;
}

int specialModeTicker = 0;
DisplayMode mmode = DisplayMode::plain;

//-----------------------------------------------------------------------------------
// loop
//-----------------------------------------------------------------------------------
void loop() {
	delay( 10 );

	// do OTA update stuff
	ArduinoOTA.handle();

	// update LEDs
	LED.setBrightness( Brightness.value() );
	LED.setTime( h, m, s, ms );
	LED.setDate( year, month, day );
	LED.process();

	// do not continue if OTA update is in progress
	// OTA callbacks drive the LED display mode and OTA progress
	// in the background, the above call to LED.process() ensures
	// the OTA status is output to the LEDs
	if( OTA_in_progress )
		return;

	// show the hourglass animation with green corners for the first 2.5 seconds
	// after boot to be able to reflash with OTA during that time window if
	// the firmware hangs afterwards
	if( updateCountdown ) {
		setLED( 0, 1, 0 );
		LED.setMode( DisplayMode::greenHourglass );
		Serial.print( "." );
		delay( 100 );
		updateCountdown--;
		if( updateCountdown == 0 ) {
			LED.setMode( Config.defaultMode );
			setLED( 0, 0, 0 );
		}
		return;
	}

	// set special mode depending on current time
	if( h == 22 && m == 00 ) {
		specialModeTicker = 600;
		LED.setMode( DisplayMode::heart );
	} else if( h == 13 && m == 37 ) {
		specialModeTicker = 600;
		LED.setMode( DisplayMode::matrix );
	} else if( h == 23 && m == 00 ) {
		specialModeTicker = 600;
		LED.setMode( DisplayMode::stars );
	}
	if( specialModeTicker-- > 0 ) {
		if( specialModeTicker == 0 ) {
			// still not clear why this leads to access exceptions?
			// fetching it in a local var first works!!
			int mx = (int)LED.mode;
			int dm = (int)Config.defaultMode;
			if( mx != dm ) {
				LED.setMode( (DisplayMode)dm );
			}
		}
	}

	// do web server stuff
	HttpServer.process();

	// save configuration to EEPROM if necessary
	// see above: cheating with "unaligned" access
	int delayed = (int)Config.delayedWriteFlag;
	if( delayed ) {
		DEBUG( "Config timer expired, writing configuration.\r\n" );
		Config.delayedWriteFlag = false;
		Config.save();
	}

	// output current time if seconds value has changed
	if( s != lastSecond ) {
		lastSecond = s;
		DEBUG( "%02i:%02i:%02i, ADC=%i, heap=%i, brightness=%i\r\n", h, m, s, Brightness.avg, ESP.getFreeHeap(),
		       Brightness.value() );
#if 0
		Serial.printf( "mmu_is_iram/dram &LED.mode: %08x : %i %i size=%i\r\n", &( LED.mode ), mmu_is_iram( &( LED.mode ) ),
		               mmu_is_dram( &( LED.mode ) ), sizeof( LED.mode ) );
		Serial.printf( "mmu_is_iram/dram &Config.delayedWriteFlag: %08x : %i %i size=%i\r\n", &( Config.delayedWriteFlag ),
		               mmu_is_iram( &( Config.delayedWriteFlag ) ), mmu_is_dram( &( Config.delayedWriteFlag ) ),
		               sizeof( Config.delayedWriteFlag ) );

		Serial.printf( "mode = %i \r\n", mx );
#endif
	}

	/* Will not work with neo pixel bus
	if( Serial.available() ) {
	  int incoming = Serial.read();
	  switch( incoming ) {
	  case 'i':
	    Serial.println( "WordClock ESP8266 ready." );
	    break;

	  case 'X':
	    WiFi.disconnect();
	    ESP.reset();
	    break;

	  default:
	    Serial.printf( "Unknown command '%c'\r\n", incoming );
	    break;
	  }
	}*/

	if( telnetServer.hasClient() ) {
		if( telnetClient.connected() ) {
			telnetClient.stop();
		}
		telnetClient = telnetServer.available();
		telnetClient.println( "WordClock telnet server ready." );
	}
}
// ./esptool.py --port /dev/tty.usbserial --baud 460800 write_flash --flash_size=8m 0
// /var/folders/yh/bv744591099f3x24xbkc22zw0000gn/T/build006b1a55228a1b90dda210fcddb62452.tmp/test.ino.bin FlashSize 1M
// (128k SPIFFS) C:\Python27\python.exe "C:\Program Files\esptool\espota.py" --ip=192.168.178.95 --port=8266 --progress
// --file=${workspace_loc}\${project_path}\Release\${project_name}.bin

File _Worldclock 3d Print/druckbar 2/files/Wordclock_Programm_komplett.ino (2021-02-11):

#include <WiFiClient.h>
#include <ESP8266WebServer.h> // Web Server service
#include <ESP8266mDNS.h>

#include <Adafruit_NeoPixel.h>
#include <time.h>             //include time.h library
#include <Wire.h>             //include Wire.h library
#include <WiFiUdp.h>          // UDP is needed for NTP server communication
//#include <WebSocketsServer.h> // Web socket server

// Date and time functions using a DS3231 RTC connected via I2C and Wire lib
#include "RTClib.h"

#ifdef __AVR__
#include <avr/power.h>
#endif

ESP8266WebServer server(80);    // Create a webserver object that listens for HTTP request on port 80
//WebSocketsServer webSocket(81); // create a websocket server on port 81

// WiFi class
//ESP8266WiFiClass wiFi8266;

// I2C adress of the RTC  DS3231 (Chip on ZS-042 Board)
int RTC_I2C_ADDRESS = 0x68;

// Arduino-Pin connected to the NeoPixels
#define PIN 12

// How many NeoPixels are attached to the Arduino?
#define NUMPIXELS  114

// Display color (RGB)
#define factor    0.3          //lightning factor
int displayR =  200  * factor; //red color value
int displayG =  40   * factor; //green color value
int displayB =  0    * factor; //blue color value

/* Don't hardwire the IP address or we won't get the benefits of the pool.
    Lookup the IP address for the host name instead */
IPAddress timeServerIP;      // IP Adress of de.pool.ntp.org time server
const char* ntpServerName = "de.pool.ntp.org";

//enter your WIFI SSID and Password below:
const char* wiFiNetworkName = "XXX";
const char* wiFiNetworkPwd  = "XXX";

const int NTP_PACKET_SIZE = 48;     // NTP time stamp is in the first 48 bytes of the message
byte packetBuffer[ NTP_PACKET_SIZE]; //buffer to hold incoming and outgoing packets


WiFiUDP udp;                        // A UDP instance to let us send and receive packets over UDP

unsigned int localPort = 2390;      // local port to listen for UDP packets

RTC_DS3231 rtc;                     // rtc communication object


// variables for RTC-module read time
int iYear,
    iMonth,
    iDay,
    iHour,
    iMinute,
    iSecond;

uint16_t val1 = NUMPIXELS;
uint16_t val2 = PIN;
uint16_t val3 = NEO_GRB + NEO_KHZ800;
Adafruit_NeoPixel pixels = Adafruit_NeoPixel(val1, val2, val3);

int delayval = 200; // delay in milliseconds

void setup() {

  // Initialize Serial Monitoring
  Serial.begin(115200);
  Serial.println("Start Monitor...");

  if (! rtc.begin()) {
    Serial.println("Couldn't find RTC");
    Serial.flush();
    abort();
  }

  // start RTC Communication via Wire.h library
  Serial.print("Start RTC communication");
  Wire.begin();

  // This initializes the NeoPixel library.
  Serial.println("Start NeoPixel library");
  pixels.begin();

  // Start WiFi
  Serial.println("Connect to WiFi and get NTP data");
  wifiConnect();

  // Start web server
  Serial.println("About to start WebServer....");
  startServer();
}


void startServer()
{

  if (MDNS.begin("esp8266")) {
    Serial.println("MDNS responder started");
  }

  Serial.println("Establish FILE NOT FOUND handler");
  server.onNotFound(handleNotFound); // if someone requests any other file or page, go to function 'handleNotFound'
  // and check if the file exists

  Serial.println("Call server.begin");
  server.begin(80); // start the HTTP server

  server.on("/", handleRoot);               // Call the 'handleRoot' function when a client requests URI "/"

  Serial.println("HTTP server started.");
}

void handleRoot() {
  Serial.println("In handle Root...");
  server.send(200, "text/plain", "This is the world best programmers WordClock! :-) ");   // Send HTTP status 200 (Ok) and send some text to the browser/client
}


/*__________________________________________________________SERVER_HANDLERS__________________________________________________________*/
void handleNotFound()
{ // if the requested file or page doesn't exist, return a 404 not found error
  if (!handleFileRead(server.uri()))
  { // check if the file exists in the flash memory (SPIFFS), if so, send it
    server.send(404, "text/plain", "404: File Not Found");
  }
}

bool handleFileRead(String path)
{ // send the right file to the client (if it exists)
  Serial.println("handleFileRead: " + path);
  if (path.endsWith("/"))
    path += "index.html";                    // If a folder is requested, send the index file
  String contentType = getContentType(path); // Get the MIME type
  String pathWithGz = path + ".gz";
  if (SPIFFS.exists(pathWithGz) || SPIFFS.exists(path))
  { // If the file exists, either as a compressed archive, or normal
    if (SPIFFS.exists(pathWithGz))                      // If there's a compressed version available
      path += ".gz";                                    // Use the compressed verion
    File file = SPIFFS.open(path, "r");                 // Open the file
    size_t sent = server.streamFile(file, contentType); // Send it to the client
    file.close();                                       // Close the file again
    Serial.println(String("\tSent file: ") + path);
    return true;
  }
  Serial.println(String("\tFile Not Found: ") + path); // If the file doesn't exist, return false
  return false;
}


String getContentType(String filename)
{
  if (filename.endsWith(".htm"))
    return "text/html";
  else if (filename.endsWith(".html"))
    return "text/html";
  else if (filename.endsWith(".css"))
    return "text/css";
  else if (filename.endsWith(".js"))
    return "application/javascript";
  else if (filename.endsWith(".ico"))
    return "image/x-icon";
  else if (filename.endsWith(".png"))
    return "image/png";
  else if (filename.endsWith(".gif"))
    return "image/gif";
  else if (filename.endsWith(".jpg"))
    return "image/jpeg";
  else if (filename.endsWith(".ico"))
    return "image/x-icon";
  else if (filename.endsWith(".xml"))
    return "text/xml";
  else if (filename.endsWith(".pdf"))
    return "application/x-pdf";
  else if (filename.endsWith(".zip"))
    return "application/x-zip";
  else if (filename.endsWith(".gz"))
    return "application/x-gzip";
  return "text/plain";
}
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

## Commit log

2018-03-22 Frontplatte Howto, Vorlage und Font hochgeladen
2018-03-22 Dateien hinzugefügt
    [180222 T HC Frontplatte groß.dwg, 180222 T HC Frontplatte groß.dxf, 180222 T HC WordClock Rasterbleche.dwg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]
2019-12-10 3d Druckbare Version
    [Lichtgitter1_2x.stl, Lichtgitter2_2x.stl, Rahmen_Kid4.stl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]
2021-08-04 - fixed number of hour glass frames - init rainbow speed
2021-08-05 - renaming auf led functions class
2021-08-06 - clean up (c++ 11 asignments) - fixed layout 2 - fillMode
    [ledfunctions.cpp, ledfunctions.h]
2021-08-06 - fixed setvar - added fillMode
    [webserver.cpp]
2021-08-07 - addded year, month, day - excluded red / green / blue onboard leds (#ifdef)
2021-12-20 - added graphics for front
    [Clock_45x45.dxf, EdelstahlFrontV2.dxf, EdelstahlFrontV2_Faktor10_vergroessert.dxf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]
2021-12-20 - added 3d prints

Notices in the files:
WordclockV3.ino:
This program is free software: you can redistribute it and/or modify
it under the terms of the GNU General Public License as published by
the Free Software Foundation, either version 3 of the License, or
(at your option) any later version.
